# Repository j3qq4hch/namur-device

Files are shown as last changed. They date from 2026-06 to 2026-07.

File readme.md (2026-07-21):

В это репозитории хранятся исходные файлы проекта промышленного контроллера с Namur-входами

## Соображения

Ниже приведена схема одного измерительного канала

<p align = center>
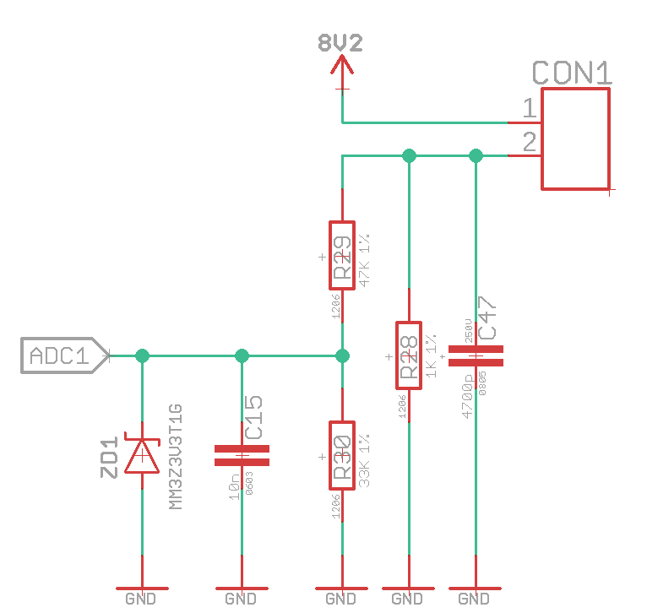
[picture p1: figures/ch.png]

</p>

Эта схема, хотя и не копирует 1 в 1, но все же весьма похожа на схему из контроллера Siemens SIMATIC ET200SP, ниже приведена картинки из [мануала](https://cache.industry.siemens.com/dl/files/246/109747246/att_921248/v1/et200sp_ha_di_16xnamur_manual_en-US_en-US.pdf) на этого контроллер (раздел 3.2).

<p align = center>
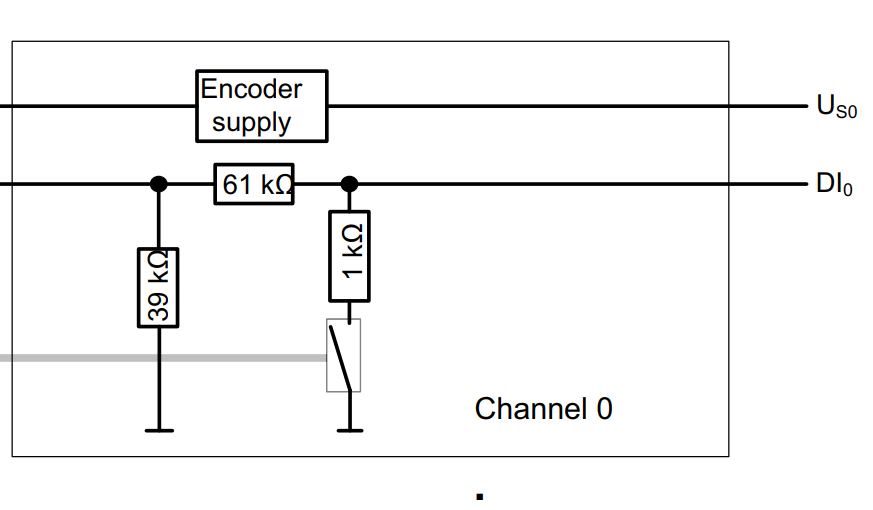
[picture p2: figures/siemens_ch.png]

</p>

Запитывать все каналы предполагается от шины питания 8.2 вольта, которая должна быть организована внутри устройства. Например, на DC-DC конвертере TPS54360:

<p align = center>
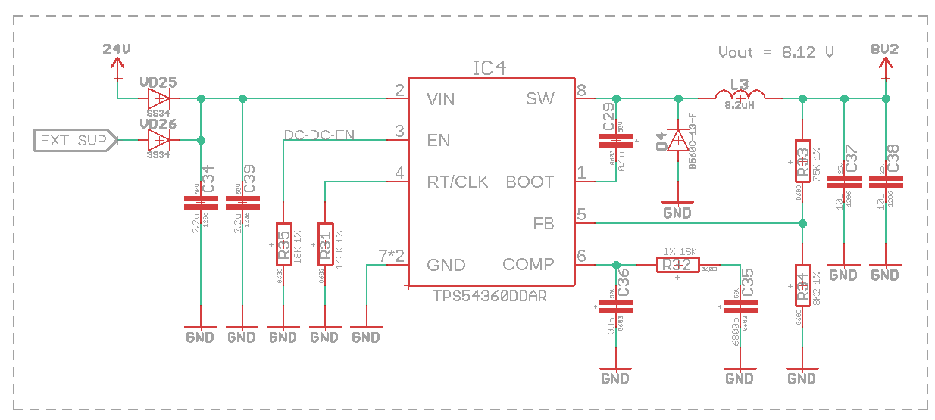
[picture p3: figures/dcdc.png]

</p>

При этом для создания шины 8.2 вольта может быть использована как внутренняя шина 24 В устройства, так и 24 вольта, подаваемые извне. 

## Количество каналов

Есть веские причины остановиться на 16 каналах для этого устройства. В пользу такого решения говорят следующие причины:

1) В этом устройстве конструктивно можно размеситить максимум 34-пиновый разъем для подключения датчиков. При этом типичный датчик имеет 2-проводную схему подключения. Хотя технически возможно увеличить количество каналов в 2 раза, монтаж в таком случае окажется крайне неряшливый и неудобный. 
2) В микроконтроллере stm32f412 16-канальный АЦП. В случае бОльшего количества каналов пришлось бы использовать дополнительные аналоговые коммутаторы. А с 16 каналами можно обойтись только микроконтроллером. Меньше BoM, проще устройство. 
3) Если на практике требуется больше 16 каналов Namur (что вообще-то не так уж и мало), можно просто установить дополнительные устройства.

## Версия на 32 канала

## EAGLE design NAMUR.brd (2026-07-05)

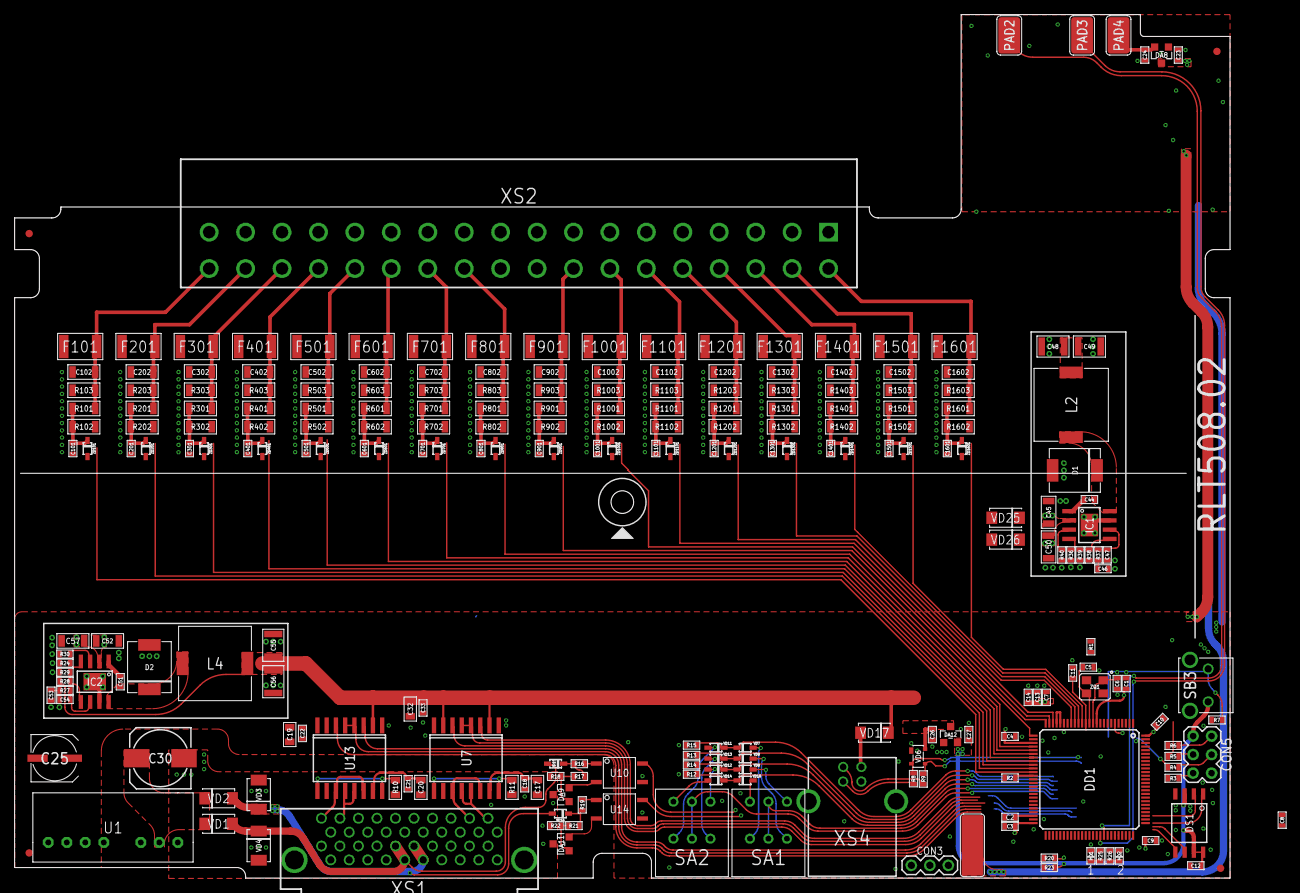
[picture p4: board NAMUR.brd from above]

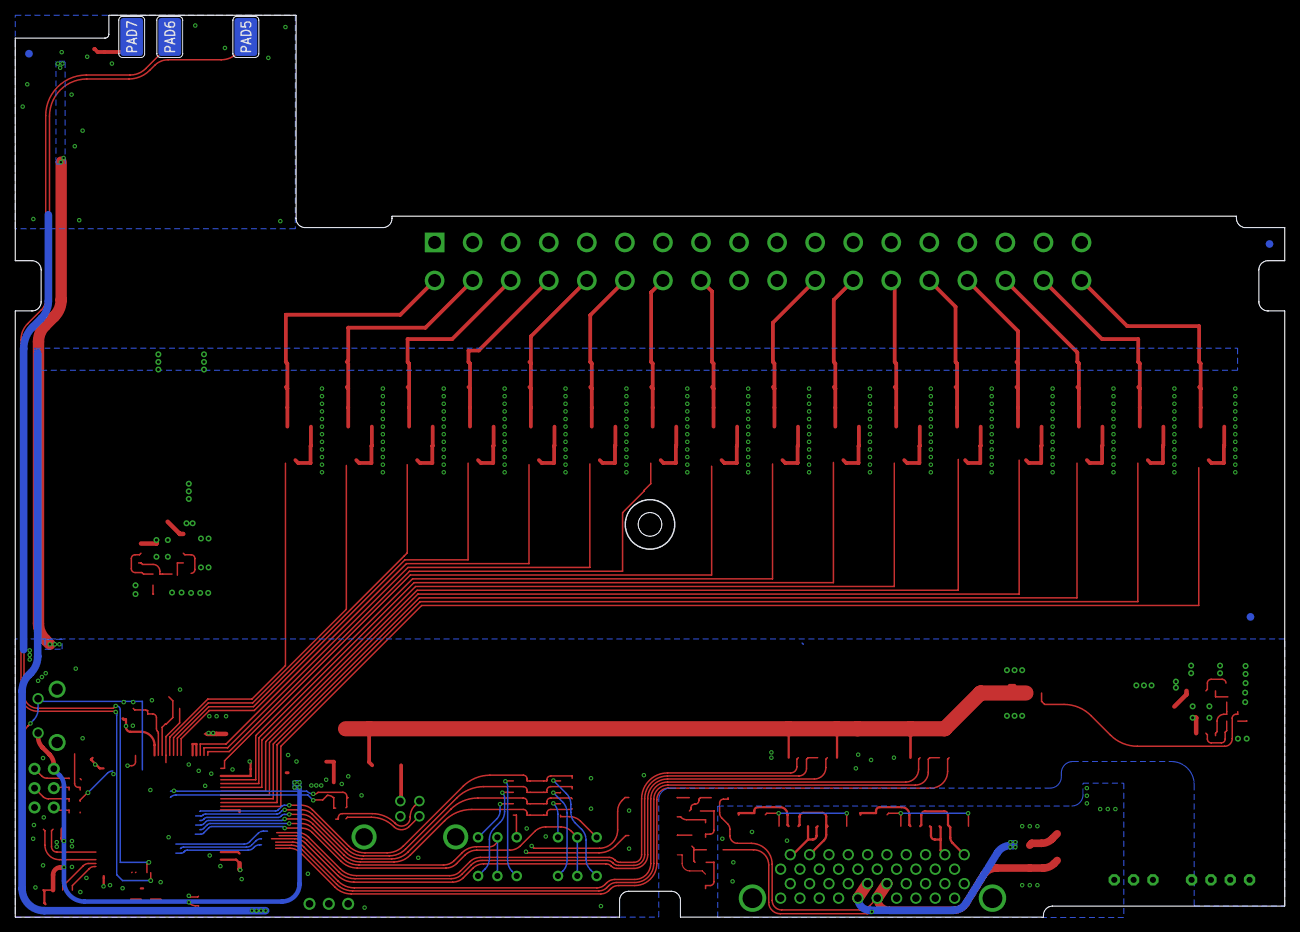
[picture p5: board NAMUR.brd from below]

Board: 4 copper layers, 166.8 x 118.5 mm, 250 parts (6 on the bottom side), 121 nets.

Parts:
C1, C3, C4, C7, C9, C10, C11, C12, C13, C18, C21, C22, C23, C24, C26, C27, C33, C44, C51: 0.1u; C0603
C2, C8: 2.2u; C0603
C5, C6: 12p; C0603
C14: 1u; C0603
C17, C19, C20, C32: 10u; C0805
C25: 22u; CAP_SMD_6.3X7.7
C30: 100u; SMD-0810
C45, C50, C52, C57: 2.2u; C1206
C46, C53: 6800p; C0603
C47, C54: 39p; C0603
C48, C49, C55, C56: 10u; C1210
C101, C201, C301, C401, C501, C601, C701, C801, C901, C1001, C1101, C1201, C1301, C1401, C1501, C1601: 10n; C0603
C102, C202, C302, C402, C502, C602, C702, C802, C902, C1002, C1102, C1202, C1302, C1402, C1502, C1602: 4700p; C1206
CON3: PINHEAD_1X03-2.54; PLS3
CON5: PINHEAD_2X03-PTH-2.54; PLD6
D1, D2: B560C; DO-214AB(SMC)
DA8, DA12: XC6206P332; SOT23-3
DA9, DA11: TL431; SOT23-3
DD1: STM32F411VCT6; LQFP100
DS1: AT25DF321A; SOIC8-208MIL
F101, F201, F301, F401, F501, F601, F701, F801, F901, F1001, F1101, F1201, F1301, F1401, F1501, F1601: SURGE_ARRESTER-S30-A90X; S30-A90X
FD1, FD2, FD3, FD4, FD5, FD6, FD7: FIDUCIALMOUNT; FIDUCIAL_MOUNT
HL1, HL2: LED-0603; LED0603
IC1, IC2: TPS54360; SOIC8-POWERPAD
L2, L4: 8.2uH; CDRH105R
PAD1: PAD-8.3X3; 8.3X3
PAD2, PAD3, PAD4, PAD5, PAD6, PAD7: PAD-5X3; 5X3
R1, R2, R7, R12, R13, R14, R15, R20, R23, R29: 10K; R0603
R3, R4, R5, R6, R8, R9: 22R; R0603
R10, R11: 000; R0805
R16, R19: 4K7; R0603
R17, R21, R38: 75K; R0603
R18, R22: 24K; R0603
R24, R36: 143K; R0603
R25, R26: 1K; R0603
R27, R30, R37, R40: 18K; R0603
R28: 53K6; R0603
R39: 8K2; R0603
R101, R201, R301, R401, R501, R601, R701, R801, R901, R1001, R1101, R1201, R1301, R1401, R1501, R1601: 47K; R1206
R102, R202, R302, R402, R502, R602, R702, R802, R902, R1002, R1102, R1202, R1302, R1402, R1502, R1602: 33K; R1206
R103, R203, R303, R403, R503, R603, R703, R803, R903, R1003, R1103, R1203, R1303, R1403, R1503, R1603: 1K; R1206
SA1, SA2: DRD16RAE04
SB3: TACT_SWITCH-KLS-KLS7-TS6606; KLS7-TS6606-5.0-180
SCR1: SCREW-M3-D3.1; PCB_SCREW_M3-D3.1
U1: URB2424S-6WR3; URB_S-6WR3
U7, U13: NSIP83086(V); SOIC16-300MIL
U10, U14: KAQY214-SOP-4; SOP-4
VD1, VD2, VD17, VD25, VD26: SS34; DO-214AC(SMA)
VD3, VD4: SMBJ24CA-SMB; DO-214AA(SMB)
VD6: PRTR5V0U2X; SOT143B
VD7, VD8, VD9, VD10, VD11, VD12, VD13, VD14: BAT54JFILM; SOD323
VD15, VD16: BAV21WS; SOD323
XS1: 1734037-4
XS2: CCDN2,5/18-G1P26THR; CCDN2.5_18-G1P26THR
XS4: USB-TYPE-B; USB-B
ZD101, ZD201, ZD301, ZD401, ZD501, ZD601, ZD701, ZD801, ZD901, ZD1001, ZD1101, ZD1201, ZD1301, ZD1401, ZD1501, ZD1601: MM3Z3V3; SOD323
ZQ1: 8MHz; OSCILLATOR-3.2X2.5-4P

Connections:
1N: R15.2, VD7.C, VD11.C
2N: R14.2, VD8.C, VD12.C
4N: R13.2, VD9.C, VD13.C
8N: R12.2, VD10.C, VD14.C
!NRST: C11.2, DD1.14, R1.1, R3.1
ADC0: C101.2, DD1.23, R101.P$1, R102.P$2, ZD101.C
ADC1: C201.2, DD1.24, R201.P$1, R202.P$2, ZD201.C
ADC2: C301.2, DD1.25, R301.P$1, R302.P$2, ZD301.C
ADC3: C401.2, DD1.26, R401.P$1, R402.P$2, ZD401.C
ADC4: C501.2, DD1.29, R501.P$1, R502.P$2, ZD501.C
ADC5: C601.2, DD1.30, R601.P$1, R602.P$2, ZD601.C
ADC6: C701.2, DD1.31, R701.P$1, R702.P$2, ZD701.C
ADC7: C801.2, DD1.32, R801.P$1, R802.P$2, ZD801.C
ADC8: C901.2, DD1.35, R901.P$1, R902.P$2, ZD901.C
ADC9: C1001.2, DD1.36, R1001.P$1, R1002.P$2, ZD1001.C
ADC10: C1101.2, DD1.15, R1101.P$1, R1102.P$2, ZD1101.C
ADC11: C1201.2, DD1.16, R1201.P$1, R1202.P$2, ZD1201.C
ADC12: C1301.2, DD1.17, R1301.P$1, R1302.P$2, ZD1301.C
ADC13: C1401.2, DD1.18, R1401.P$1, R1402.P$2, ZD1401.C
ADC14: C1501.2, DD1.33, R1501.P$1, R1502.P$2, ZD1501.C
ADC15: C1601.2, DD1.34, R1601.P$1, R1602.P$2, ZD1601.C
BOOT0: DD1.94, R7.2, SB3.1
BOOT1: DD1.37, R2.2
BOOT4: C44.1, IC1.1
BOOT5: C51.1, IC2.1
CN1: SA1.C_1, SA1.C_2
CN2: SA2.C_1, SA2.C_2
DIN: C45.P$2, C50.P$2, IC1.2, VD25.C, VD26.C
EN: IC1.3, IC2.3, R30.2, R40.2
GND: C1.1, C2.1, C3.1, C4.1, C5.1, C6.2, C7.1, C8.1, C9.1, C10.2, C11.1, C12.1, C13.1, C14.1, C19.1, C22.1, C23.1, C24.1, C25.-, C26.1, C27.1, C32.1, C33.1, C45.P$1, C46.1, C47.1, C48.1, C49.1, C50.P$1, C52.P$1, C53.1, C54.1, C55.1, C56.1, C57.P$1, C101.1, C102.P$1, C201.1, C202.P$1, C301.1, C302.P$1, C401.1, C402.P$1, C501.1, C502.P$1, C601.1, C602.P$1, C701.1, C702.P$1, C801.1, C802.P$1, C901.1, C902.P$1, C1001.1, C1002.P$1, C1101.1, C1102.P$1, C1201.1, C1202.P$1, C1301.1, C1302.P$1, C1401.1, C1402.P$1, C1501.1, C1502.P$1, C1601.1, C1602.P$1, CON3.1, CON5.6, D1.A, D2.A, DA8.1, DA12.1, DD1.10, DD1.20, DD1.27, DD1.49, DD1.74, DD1.99, DS1.4, HL1.C, HL2.C, IC1.7, IC1.POWERPAD, IC2.7, IC2.POWERPAD, PAD5.P$1, PAD6.P$1, PAD7.P$1, R2.1, R7.1, R12.1, R13.1, R14.1, R15.1, R24.1, R29.1, R30.1, R36.1, R39.1, R40.1, R102.P$1, R103.P$1, R202.P$1, R203.P$1, R302.P$1, R303.P$1, R402.P$1, R403.P$1, R502.P$1, R503.P$1, R602.P$1, R603.P$1, R702.P$1, R703.P$1, R802.P$1, R803.P$1, R902.P$1, R903.P$1, R1002.P$1, R1003.P$1, R1102.P$1, R1103.P$1, R1202.P$1, R1203.P$1, R1302.P$1, R1303.P$1, R1402.P$1, R1403.P$1, R1502.P$1, R1503.P$1, R1602.P$1, R1603.P$1, U1.7, U7.1, U7.8, U10.3, U13.1, U13.8, U14.3, VD6.1, XS4.4, XS4.5_1, XS4.5_2, ZD101.A, ZD201.A, ZD301.A, ZD401.A, ZD501.A, ZD601.A, ZD701.A, ZD801.A, ZD901.A, ZD1001.A, ZD1101.A, ZD1201.A, ZD1301.A, ZD1401.A, ZD1501.A, ZD1601.A, ZQ1.2, ZQ1.4
GNDD: F101.2, F201.2, F301.2, F401.2, F501.2, F601.2, F701.2, F801.2, F901.2, F1001.2, F1101.2, F1201.2, F1301.2, F1401.2, F1501.2, F1601.2, PAD1.P$1
I2C3_SCL: DD1.67, PAD2.P$1
I2C3_SDA: DD1.66, PAD3.P$1
ISO24V: C30.+, U1.2, VD1.C, VD2.C
MCU_RX1: DD1.69, U13.3
MCU_RX6: DD1.64, U7.3
MCU_TX1: DD1.68, U13.6
MCU_TX6: DD1.63, U7.6
unnamed: C2.2, DD1.48
unnamed: C8.2, DD1.73
unnamed: CON5.5, R3.2
unnamed: C6.1, DD1.12, ZQ1.1
unnamed: C5.2, DD1.13, ZQ1.3
unnamed: CON5.4, R4.2
unnamed: CON5.3, R5.2
unnamed: CON5.2, R6.2
unnamed: DA9.2, U10.2
unnamed: DA9.1, R17.2, R18.1
unnamed: R16.1, U10.1
unnamed: R16.2, R17.1, VD15.C
unnamed: HL1.A, R25.2
unnamed: DA11.2, U14.2
unnamed: DA11.1, R21.2, R22.1
unnamed: R19.1, U14.1
unnamed: R19.2, R21.1, VD16.C
unnamed: HL2.A, R26.2
unnamed: IC1.4, R36.2
unnamed: C47.2, IC1.6, R37.2
unnamed: C46.2, R37.1
unnamed: IC1.5, R38.1, R39.2
unnamed: IC2.4, R24.2
unnamed: C54.2, IC2.6, R27.2
unnamed: C53.2, R27.1
unnamed: IC2.5, R28.1, R29.2
unnamed: R11.2, U7.9, U7.16
unnamed: C20.1, C21.1, U13.15
unnamed: C24.2, DA8.2, PAD4.P$1
unnamed: VD1.A, VD4.C, VD15.A, XS1.A5, XS1.B5
unnamed: VD2.A, VD3.C, VD16.A, XS1.A6, XS1.B6
unnamed: U7.11, U7.14, XS1.D9
unnamed: U7.12, U7.13, XS1.D10
unnamed: R10.2, U13.9, U13.16
unnamed: R9.2, XS4.2
unnamed: R8.2, XS4.3
unnamed: VD17.A, XS4.1
unnamed: U13.11, U13.14, XS1.D1
unnamed: U13.12, U13.13, XS1.D2
unnamed: C17.1, C18.1, U7.15
unnamed: SA1.1, VD7.A
unnamed: SA1.2, VD8.A
unnamed: SA1.4, VD9.A
unnamed: SA1.8, VD10.A
unnamed: SA2.1, VD11.A
unnamed: SA2.2, VD12.A
unnamed: SA2.4, VD13.A
unnamed: SA2.8, VD14.A
NAMUR0: C102.P$2, F101.1, R101.P$2, R103.P$2, XS2.B18
NAMUR1: C202.P$2, F201.1, R201.P$2, R203.P$2, XS2.B17
NAMUR2: C302.P$2, F301.1, R301.P$2, R303.P$2, XS2.B16
NAMUR3: C402.P$2, F401.1, R401.P$2, R403.P$2, XS2.B15
NAMUR4: C502.P$2, F501.1, R501.P$2, R503.P$2, XS2.B14
NAMUR5: C602.P$2, F601.1, R601.P$2, R603.P$2, XS2.B13
NAMUR6: C702.P$2, F701.1, R701.P$2, R703.P$2, XS2.B12
NAMUR7: C802.P$2, F801.1, R801.P$2, R803.P$2, XS2.B11
NAMUR8: C902.P$2, F901.1, R901.P$2, R903.P$2, XS2.B8
NAMUR9: C1002.P$2, F1001.1, R1001.P$2, R1003.P$2, XS2.B7
NAMUR10: C1102.P$2, F1101.1, R1101.P$2, R1103.P$2, XS2.B6
NAMUR11: C1202.P$2, F1201.1, R1201.P$2, R1203.P$2, XS2.B5
NAMUR12: C1302.P$2, F1301.1, R1301.P$2, R1303.P$2, XS2.B4
NAMUR13: C1402.P$2, F1401.1, R1401.P$2, R1403.P$2, XS2.B3
NAMUR14: C1502.P$2, F1501.1, R1501.P$2, R1503.P$2, XS2.B2
NAMUR15: C1602.P$2, F1601.1, R1601.P$2, R1603.P$2, XS2.B1
PGND: C17.2, C18.2, C20.2, C21.2, C30.-, DA9.3, DA11.3, R10.1, R11.1, R18.2, R22.2, U1.1, VD3.A, VD4.A, XS1.A1, XS1.A2, XS1.A3, XS1.A4, XS1.A7, XS1.A8, XS1.A9, XS1.B1, XS1.B2, XS1.B3, XS1.B4, XS1.B7, XS1.B8, XS1.B9, XS1.C4, XS1.C5, XS1.C6, XS1.C7, XS1.C8, XS1.D3, XS1.D6
REDE1: U13.4, U13.5
REDE2: DD1.65, U7.4, U7.5
SPI2_CLK: DD1.52, DS1.6
SPI2_CS: DD1.51, DS1.1
SPI2_MISO: DD1.53, DS1.2
SPI2_MOSI: DD1.54, DS1.5
SW10: C51.2, D2.C, IC2.8, L4.1
SW11: C44.2, D1.C, IC1.8, L2.1
SWC: DD1.76, R5.1
SWD: DD1.72, R6.1
U1TS: R20.1, U10.4
U2TS: R23.1, U14.4
USB_DM: DD1.70, R9.1, VD6.3
USB_DP: DD1.71, R8.1, VD6.2
VDD_3V3: C1.2, C3.2, C4.2, C7.2, C9.2, C10.1, C12.2, C13.2, C14.2, C27.2, CON5.1, DA12.2, DD1.6, DD1.11, DD1.21, DD1.22, DD1.28, DD1.50, DD1.75, DD1.100, DS1.3, DS1.7, DS1.8, R1.2, R20.2, R23.2, SB3.2
VDD_5V: C19.2, C22.2, C23.2, C26.2, C32.2, C33.2, C55.2, C56.2, DA8.3, DA12.3, L4.2, R28.2, U7.2, U7.7, U13.2, U13.7, VD6.4, VD17.C
VDD_8V2: C48.2, C49.2, L2.2, R38.2, XS2.A1, XS2.A2, XS2.A3, XS2.A4, XS2.A5, XS2.A6, XS2.A7, XS2.A8, XS2.A9, XS2.A10, XS2.A11, XS2.A12, XS2.A13, XS2.A14, XS2.A15, XS2.A16, XS2.A17, XS2.A18
VDD_24V: C25.+, C52.P$2, C57.P$2, IC2.2, U1.6, VD25.A
